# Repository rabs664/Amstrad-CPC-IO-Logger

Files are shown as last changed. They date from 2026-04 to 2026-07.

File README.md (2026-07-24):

# Amstrad-CPC-IO-Logger

V2_0

>[!CAUTION]
>USE AT YOUR OWN RISK.
>There is always the risk that this Amstrad CPC IO Logger could cause harm to your CPC. Although I have tested the Amstrad CPC IO Logger, there is no guarantee that it will work properly under all circumstances.

>[!WARNING]
>This project is still in development and has only been made public to share the ideas and solicit feedback. I am no expert in this area and the project should not be used as a baseline example but more an idea of what can be done with the Pico.

## Outline
This Amstrad CPC IO Logger is an external device which allows values written to the Gate Array and the CRTC to be retrieved. This can be useful, for example, for a debugger that exposes the state of these chips in a dedicated UI section.

Port &7F is used by the Gate Array and is write-only. On a standard Amstrad CPC, there is no ability to read back the values sent to the Gate Array (video mode, pen colours, ROM/RAM configuration, etc.). The firmware keeps a shadow copy of all written values in RAM for its own internal use, but many programs bypass the firmware entirely for such operations.

Port &BF can be used to read values from the CRTC, but only on certain CRTC types, and even then, only a subset of registers is readable. The firmware only maintains a shadow copy of R12–R13 (display start address). The remaining registers cannot be read back reliably across all machines, as behaviour varies depending on the CRTC type installed.

## Summary
The Amstrad CPC only uses the top 8 address lines, A8-A15, to address standard IO devices, as illustrated below. For more information please refer to the [CPC Wiki Default IO Port Summary page](https://www.cpcwiki.eu/index.php/Default_I/O_Port_Summary). To see a list of all known ports please refer to the [CPC Wiki IO Port Summary page](https://www.cpcwiki.eu/index.php/I/O_Port_Summary). This Amstrad CPC IO logger then captures A8-A15 and D0-D7 associated with any IO Write that occurs (i.e. a Z80 OUT instruction). Any IO Writes associated with the Gate Array or CRTC are captured and can be retrieved at any point with a series of simple IO Reads to the Amstrad CPC IO logger (i.e. a Z80 IN instruction).

Amstrad CPC IO Addressing

## Design Summary
The discrete 74 series logic associated with Amstrad CPC IO Logger PCB presents two signals* to the Pico;
- IOWR: Active low on an IO Write instruction from the Amstrad CPC
- CSRD: Active low when on an IO read instruction from the Amstrad CPC for the Amstrad CPC IO Logger IO Address.

Amstrad CPC IO Logger Design

### Capture
When IOWR goes low, State Machine 1 (SM1) will push the contents of A8-A15** and D0-D7 onto its RX FIFO. DMA1 detects this and places the data into a Capture Buffer. Note that the Capture buffer is configured as a Rig Buffer.

**A0-A1 are also capture but are not used.

The contents of the Capture Buffer is decoded and the CRTC and Gate Array Register write values are placed into a Register Buffer.

### Timing
When data is placed into the Capture Buffer it is timed stamped in the Timing Buffer with time since start in micro seconds.

### Retrieve
When CSRD goes low after an IN instruction (i.e. after INP(&F9E0) from BASIC), SM2 places a transfer count of 1 on it's RX FIFO. DMA2 detects this and places this value into the Transfer Count Trigger of DMA3. DMA3 detects this and then places the next register value from the Register Buffer onto the TX FIFO of SM2. This is then returned back to the Amstrad CPC. Repeated IN instructions will return the next value in the Register Buffer.

### Register Buffer
The Register Buffer is a sequential list of register values written to the CRTC and Gate Array. Each IN instruction to the Amstrad CPC IO Logger will return the next value in the Register Buffer. An OUT instruction of 0 (i.e. OUT &F9E0,0 from BASIC) will reset the sequence back to the first value in the Register Buffer (i.e. CRTC R0). Equally an OUT instruction of 0 to 43 will set the position in the Register Buffer from which the next IN instruction will retrieve data. Note the Register Buffer is 64 bytes in size and a Ring Buffer, so values past 43 (the ERR Register) will return an uninitialized value until the retrieval position wraps.

Register Buffer V2

- LR is the last CRTC Register written to.
- LP is the last GA Pen written to.
- P16 is the Border Pen
- ERR is a decode error flag generated by the Amstrad CPC IO Logger (still under development).

Please refer to the [CPC Wiki CRTC page](https://www.cpcwiki.eu/index.php/CRTC) and [CPC Wiki Gate Array page](https://www.cpcwiki.eu/index.php/Gate_Array) for more information.

### Pen Colour Values
The Pen Colour values returned do not include the 3 bit command value 010. See INKR Values in the Info folder. 

### Debug
Debug output to a console (i.e. putty) can be enabled within the code and controlled from the Amstrad CPC with an OUT instruction between 50 and 57 (i.e. OUT &F9E0,50 will print the contents of the Register Buffer to the console). See the main code for more information.

Debug

Debug commands.

| Debug |Value| Log Header |
| ---|-----|---|
| PRINT_REG_BUFFER | 50  | REGBF |
| TOGGLE_PRINT_CRTC_INDEX | 51  | CRTCI |
| TOGGLE_PRINT_CRTC_DATA | 52  | CRTCD |
| TOGGLE_GA_PEN | 53  | GAPEN |
| TOGGLE_GA_COL | 54  | GACOL |
| TOGGLE_GA_RMR | 55  | GARMR |
| TOGGLE_GA_MMR | 56  | GAMMR |
| TOGGLE_GA_RMR2 | 57  | GARM2 |
| TOGGLE_IO_LOG | 58  | IOLOG |
| TOGGLE_CRTC_DATA_TIMING_V1 | 59  | |
| TOGGLE_CRTC_DATA_TIMING_V2 | 60  | |

### CRTC Register Logging
IO Writes to the CRTC Register Logging can be enabled using OUT &F9E0,60 (OUT &F9E0,60 again will disable the logging).

When enabled the time stamped writes to the CRTC Registered will be loggged over USB. The logging includes a time since last write in micro seconds, the register number, the value written (in hex) and a "lag-o-meter".

The "lag-o-meter" is a value from 1 to 10 indicating the decode lag behind the capture. A value of 1 is no lag and a value of 10 implies the decode has been overrun and data may be lost.

CRTC Register Logging

### Debug Command Logging
The logging of debug Commands sent to the CPC IO Logger from the CPC using OUT &F9E0 can be enabled using OUT &F9E0,58.

## Testing
Only first pass testing has so far been completed on an Amstrad CPC 6128 but the concept is working. More comprehensive testing, including error conditions is still to be completed.

Below is the output from the sample BASIC program in the repository.

Example BASIC program

## IO Address
By default the IO address used in the repository is set to F9E0. The following IO Address can be selected

- F8E0
- F8F0
- F9E0
- F9F0

Address Jumper Settings

## Project History
### 06 June 2026
Removed V1.1 of the PCB
### 17 April 2026 
CRTC Register Logging
### 26 June 2026
Found a small problem with the IO Address Selection when sending Debug Commands to the Pico. see Issue 2 V2.0 in progress
### 24 July 2026
Updated V2.0 of the PCB

## Acknowledgements
- **NoRecess** for the inspiration and support on this project.
- **RHD** members for support and encouragement.
- **Petersfield Men's Shed IT and Electronics Group** members for support and encouragement.
- **CPC Wiki** for the great information.
- **TinWhisker** for the Simple Pico CDC example

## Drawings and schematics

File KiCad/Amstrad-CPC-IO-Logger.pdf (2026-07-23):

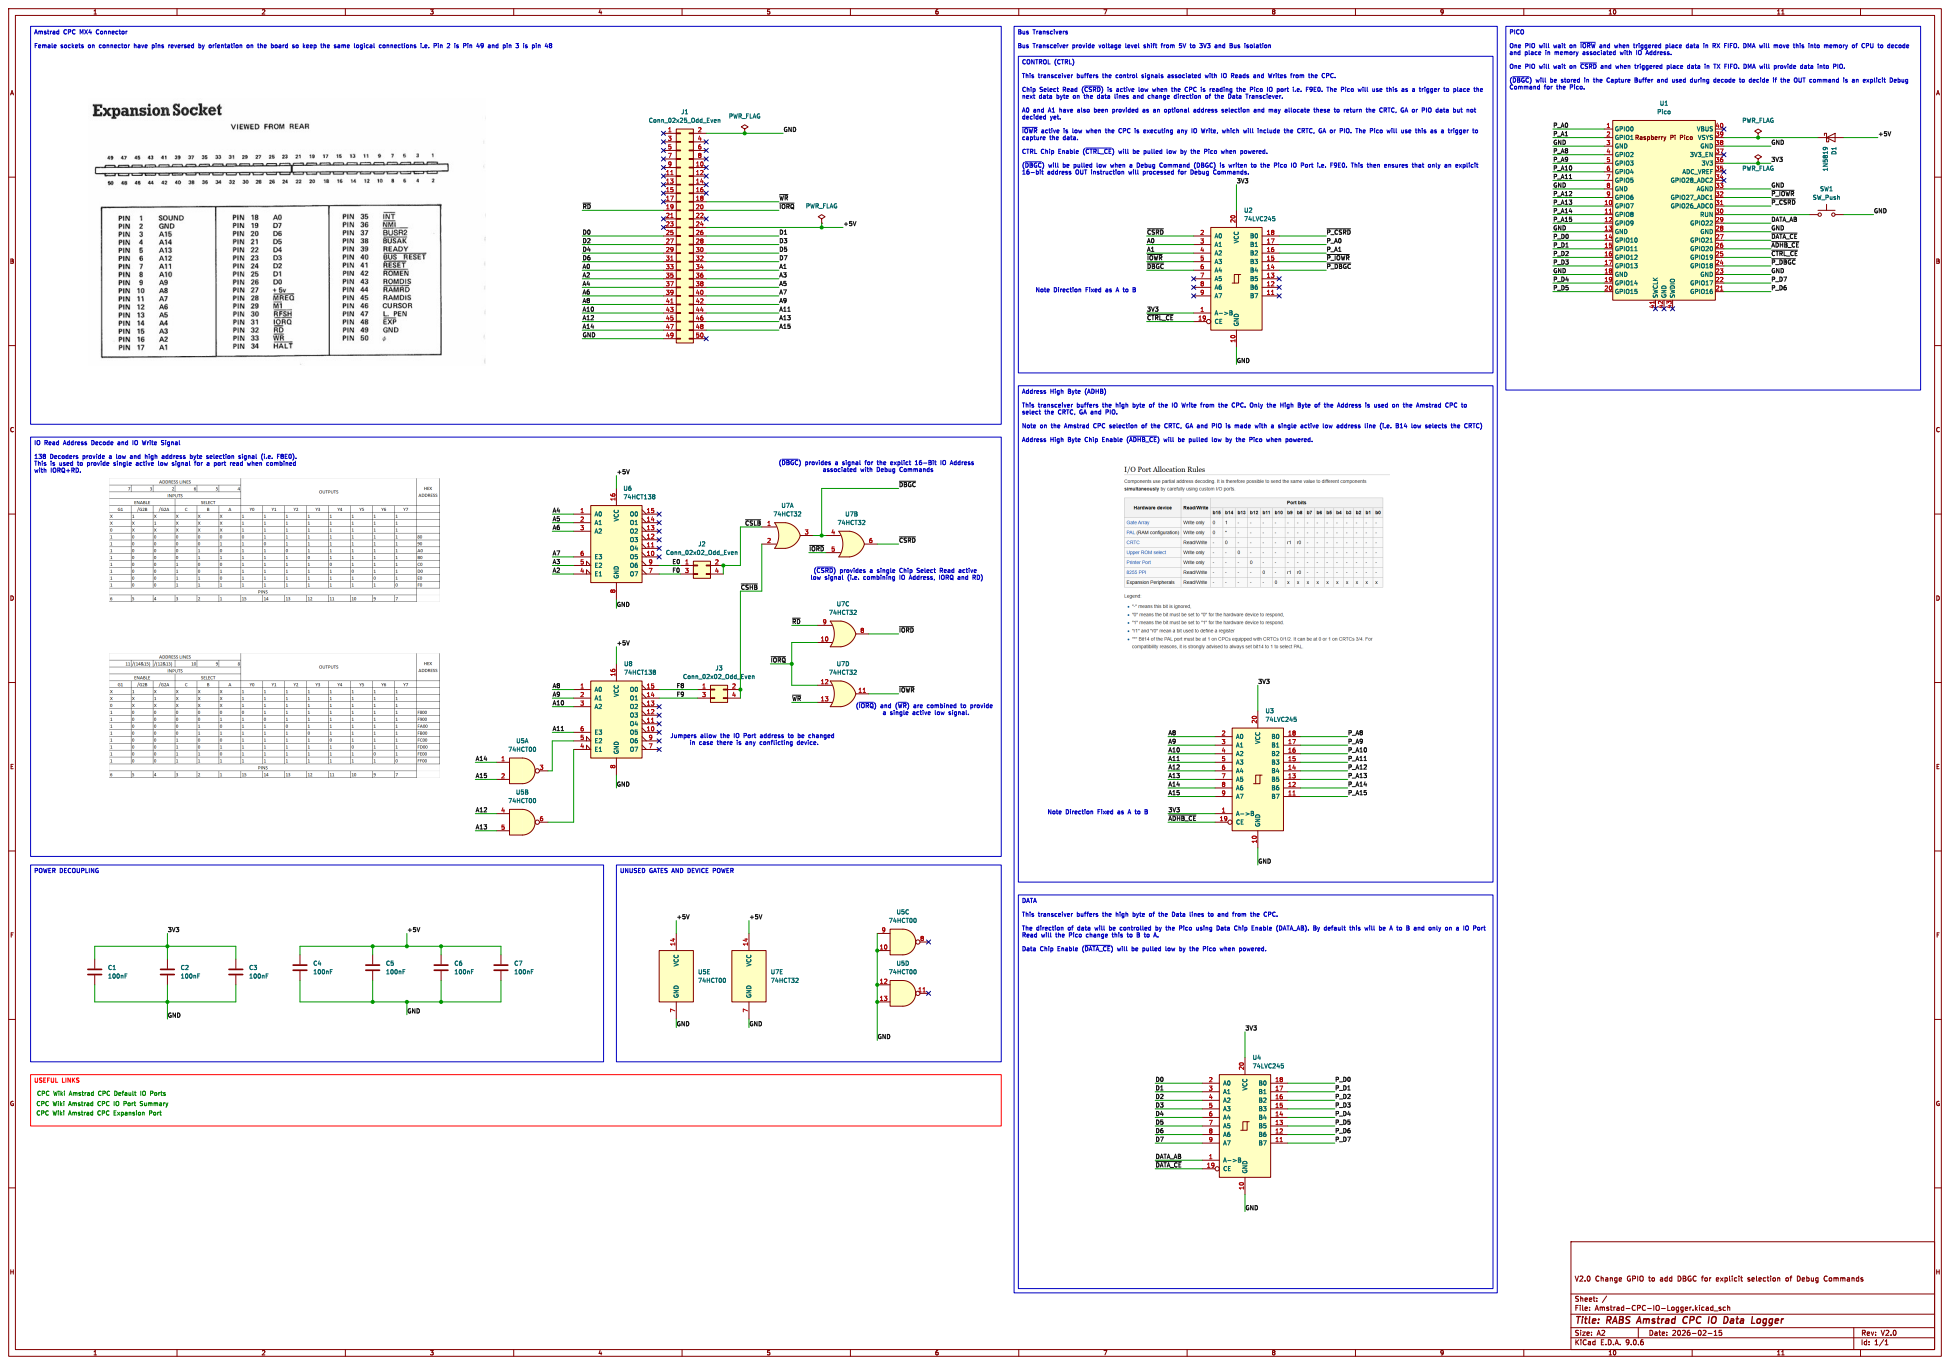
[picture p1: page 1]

capture the data. CTRL Chip Enable (~{CTRL_CE})will be pulled low by the Pico when powered.
~{CTRL_CE} 3V3 ~{IOWR} A0A1~{CSRD}

(~{CSRD})provides a single Chip Select Read active

a single active low signal.

Jumpers allow the IO Port address to be changed

CPC Wiki Amstrad CPC Default IO Ports (https://www.cpcwiki.eu/index.php/Default_I/O_Port_Summary)
CPC Wiki Amstrad CPC IO Port Summary (https://www.cpcwiki.eu/index.php/I/O_Port_Summary)

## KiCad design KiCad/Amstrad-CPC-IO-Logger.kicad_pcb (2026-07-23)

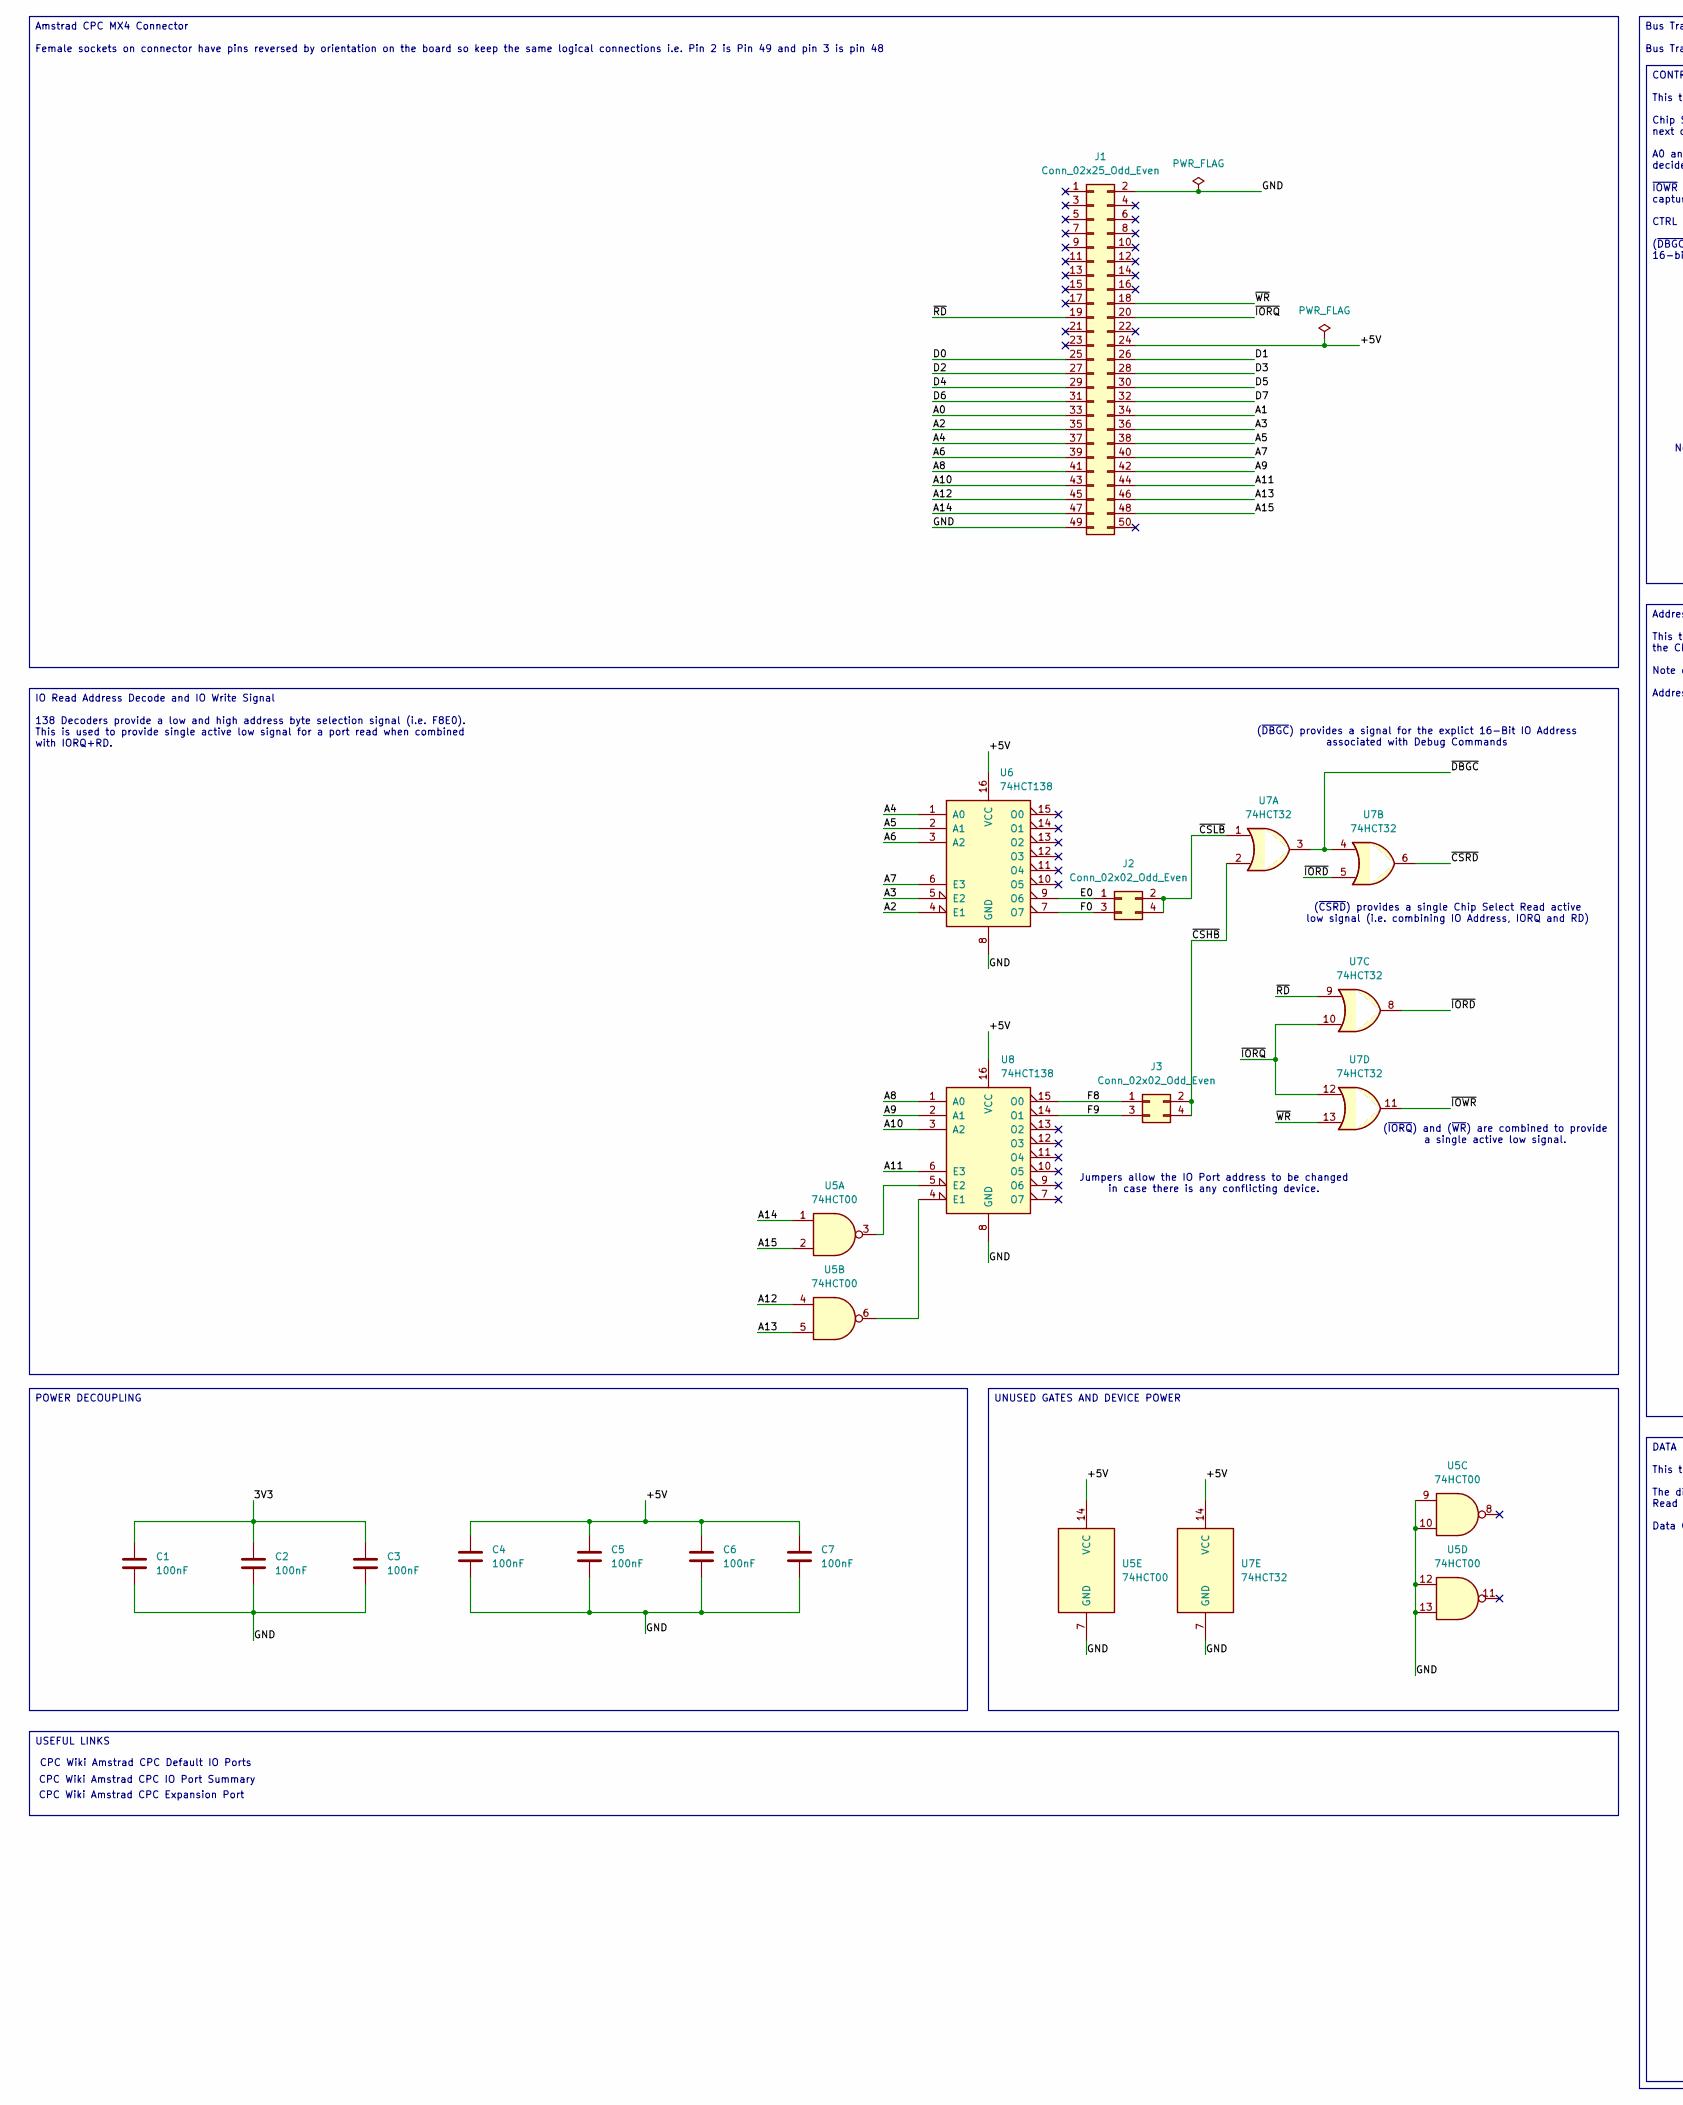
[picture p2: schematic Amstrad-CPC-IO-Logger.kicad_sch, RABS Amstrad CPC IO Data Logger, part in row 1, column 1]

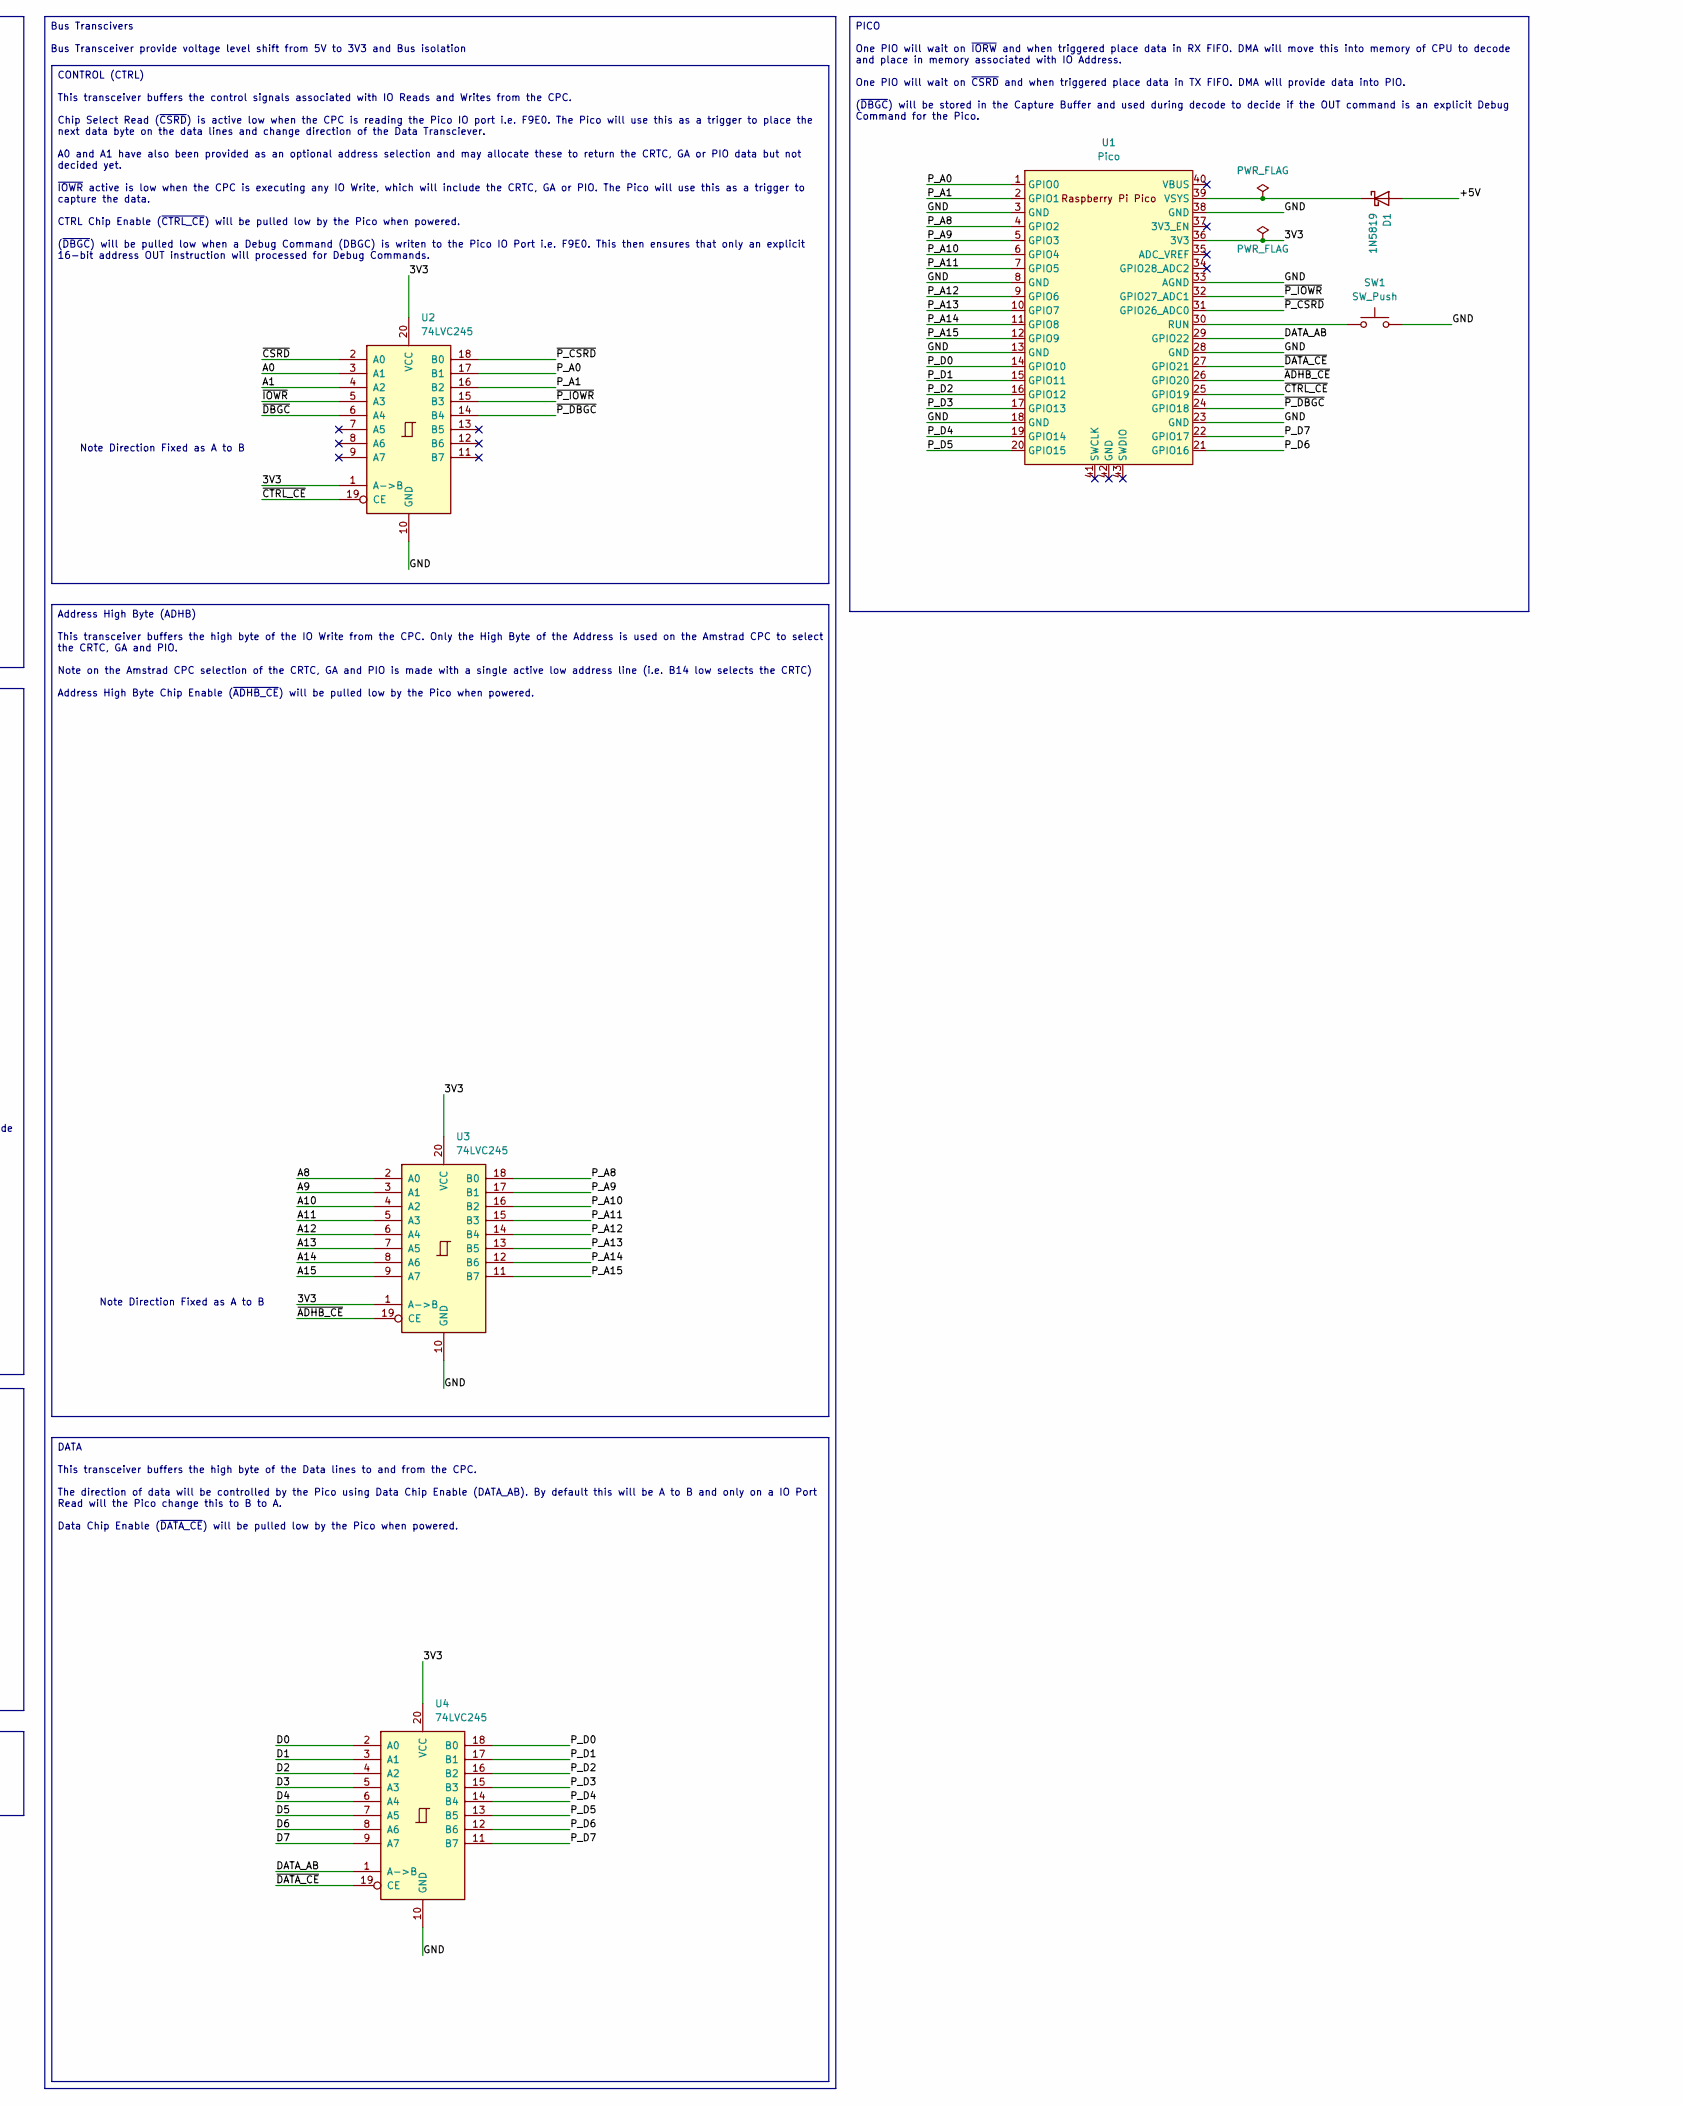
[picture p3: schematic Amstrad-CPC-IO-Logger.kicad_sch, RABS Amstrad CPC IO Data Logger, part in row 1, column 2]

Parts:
C1, C2, C3, C4, C5, C6, C7: 100nF; C_Disc_D5.0mm_W2.5mm_P5.00mm; DigiKey 56-K104K15X7RF53H5G-ND
D1: 1N5819; D_DO-41_SOD81_P10.16mm_Horizontal
J1: Conn_02x25_Odd_Even; IDC-Header_2x25_P2.54mm_Horizontal; DigiKey 3M157291-ND
J2, J3: Conn_02x02_Odd_Even; PinHeader_2x02_P2.54mm_Vertical
SW1: SW_Push; SW_PUSH_6mm
U1: Pico; RPi_Pico_SMD_TH
U2, U3, U4: 74LVC245; DIP-20_W7.62mm_Socket_LongPads
U5: 74HCT00; DIP-14_W7.62mm_Socket_LongPads; DigiKey 296-2081-5-ND
U6, U8: 74HCT138; DIP-16_W7.62mm_Socket_LongPads; DigiKey 296-2091-5-ND
U7: 74HCT32; DIP-14_W7.62mm_Socket_LongPads; Digikey 296-2112-5-ND

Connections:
/3V3: C1.1, C2.1, C3.1, U1.36 (3V3), U2.1 (A->B), U2.20 (VCC), U3.1 (A->B), U3.20 (VCC), U4.20 (VCC)
/+5V: C4.1, C5.1, C6.1, C7.1, D1.2 (A), J1.24, U5.14 (VCC), U6.16 (VCC), U7.14 (VCC), U8.16 (VCC)
/A0: J1.33, U2.3 (A1)
/A1: J1.34, U2.4 (A2)
/A2: J1.35, U6.4 (E1)
/A3: J1.36, U6.5 (E2)
/A4: J1.37, U6.1 (A0)
/A5: J1.38, U6.2 (A1)
/A6: J1.39, U6.3 (A2)
/A7: J1.40, U6.6 (E3)
/A8: J1.41, U3.2 (A0), U8.1 (A0)
/A9: J1.42, U3.3 (A1), U8.2 (A1)
/A10: J1.43, U3.4 (A2), U8.3 (A2)
/A11: J1.44, U3.5 (A3), U8.6 (E3)
/A12: J1.45, U3.6 (A4), U5.4
/A13: J1.46, U3.7 (A5), U5.5
/A14: J1.47, U3.8 (A6), U5.1
/A15: J1.48, U3.9 (A7), U5.2
/D0: J1.25, U4.2 (A0)
/D1: J1.26, U4.3 (A1)
/D2: J1.27, U4.4 (A2)
/D3: J1.28, U4.5 (A3)
/D4: J1.29, U4.6 (A4)
/D5: J1.30, U4.7 (A5)
/D6: J1.31, U4.8 (A6)
/D7: J1.32, U4.9 (A7)
/DATA_AB: U1.29 (GPIO22), U4.1 (A->B)
/E0: J2.1, U6.9 (O6)
/F0: J2.3, U6.7 (O7)
/F8: J3.1, U8.15 (O0)
/F9: J3.3, U8.14 (O1)
/GND: C1.2, C2.2, C3.2, C4.2, C5.2, C6.2, C7.2, J1.2, J1.49, SW1.2, U1.3 (GND), U1.8 (GND), U1.13 (GND), U1.18 (GND), U1.23 (GND), U1.28 (GND), U1.33 (AGND), U1.38 (GND), U2.10 (GND), U3.10 (GND), U4.10 (GND), U5.7 (GND), U5.9, U5.10, U5.12, U5.13, U6.8 (GND), U7.7 (GND), U8.8 (GND)
/P_A0: U1.1 (GPIO0), U2.17 (B1)
/P_A1: U1.2 (GPIO1), U2.16 (B2)
/P_A8: U1.4 (GPIO2), U3.18 (B0)
/P_A9: U1.5 (GPIO3), U3.17 (B1)
/P_A10: U1.6 (GPIO4), U3.16 (B2)
/P_A11: U1.7 (GPIO5), U3.15 (B3)
/P_A12: U1.9 (GPIO6), U3.14 (B4)
/P_A13: U1.10 (GPIO7), U3.13 (B5)
/P_A14: U1.11 (GPIO8), U3.12 (B6)
/P_A15: U1.12 (GPIO9), U3.11 (B7)
/P_D0: U1.14 (GPIO10), U4.18 (B0)
/P_D1: U1.15 (GPIO11), U4.17 (B1)
/P_D2: U1.16 (GPIO12), U4.16 (B2)
/P_D3: U1.17 (GPIO13), U4.15 (B3)
/P_D4: U1.19 (GPIO14), U4.14 (B4)
/P_D5: U1.20 (GPIO15), U4.13 (B5)
/P_D6: U1.21 (GPIO16), U4.12 (B6)
/P_D7: U1.22 (GPIO17), U4.11 (B7)
/~ADHB_CE: U1.26 (GPIO20), U3.19 (CE)
/~CSHB: J3.2, J3.4, U7.2
/~CSLB: J2.2, J2.4, U7.1
/~CSRD: U2.2 (A0), U7.6
/~CTRL_CE: U1.25 (GPIO19), U2.19 (CE)
/~DATA_CE: U1.27 (GPIO21), U4.19 (CE)
/~DBGC: U2.6 (A4), U7.3, U7.4
/~IORD: U7.5, U7.8
/~IORQ: J1.20, U7.10, U7.12
/~IOWR: U2.5 (A3), U7.11
/~P_CSRD: U1.31 (GPIO26_ADC0), U2.18 (B0)
/~P_DBGC: U1.24 (GPIO18), U2.14 (B4)
/~P_IOWR: U1.32 (GPIO27_ADC1), U2.15 (B3)
/~RD: J1.19, U7.9
/~WR: J1.18, U7.13
unnamed: D1.1 (K), U1.39 (VSYS)
unnamed: SW1.1, U1.30 (RUN)
unnamed: U5.6, U8.4 (E1)
unnamed: U5.3, U8.5 (E2)

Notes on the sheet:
CPC Wiki Amstrad CPC Expansion Port
CPC Wiki Amstrad CPC IO Port Summary
Note Direction Fixed as A to B
(~{CSRD}) provides a single Chip Select Read active low signal (i.e. combining IO Address, IORQ and RD)
(~{IORQ}) and (~{WR}) are combined to provide a single active low signal.
CPC Wiki Amstrad CPC Default IO Ports
Jumpers allow the IO Port address to be changed in case there is any conflicting device.
(~{DBGC}) provides a signal for the explict 16-Bit IO Address associated with Debug Commands
Amstrad CPC MX4 Connector Female sockets on connector have pins reversed by orientation on the board so keep the same logical connections i.e. Pin 2 is Pin 49 and pin 3 is pin 48
USEFUL LINKS
UNUSED GATES AND DEVICE POWER
PICO One PIO will wait on ~{IORW} and when triggered place data in RX FIFO. DMA will move this into memory of CPU to decode and place in memory associated with IO Address. One PIO will wait on ~{CSRD} and when triggered place data in TX FIFO. DMA will provide data into PIO. (~{DBGC}) will be stored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
CONTROL (CTRL) This transceiver buffers the control signals associated with IO Reads and Writes from the CPC. Chip Select Read (~{CSRD}) is active low when the CPC is reading the Pico IO port i.e. F9E0. The Pico will use this as a trigger to place the next data byte on the data lines and change dir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
Address High Byte (ADHB) This transceiver buffers the high byte of the IO Write from the CPC. Only the High Byte of the Address is used on the Amstrad CPC to select the CRTC, GA and PIO. Note on the Amstrad CPC selection of the CRTC, GA and PIO is made with a single active low address line (i.e. B1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
DATA This transceiver buffers the high byte of the Data lines to and from the CPC. The direction of data will be controlled by the Pico using Data Chip Enable (DATA_AB). By default this will be A to B and only on a IO Port Read will the Pico change this to B to A. Data Chip Enable (~{DATA_CE}) will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
POWER DECOUPLING
IO Read Address Decode and IO Write Signal 138 Decoders provide a low and high address byte selection signal (i.e. F8E0). This is used to provide single active low signal for a port read when combined with IORQ+RD.
Bus Transcivers Bus Transceiver provide voltage level shift from 5V to 3V3 and Bus isolation

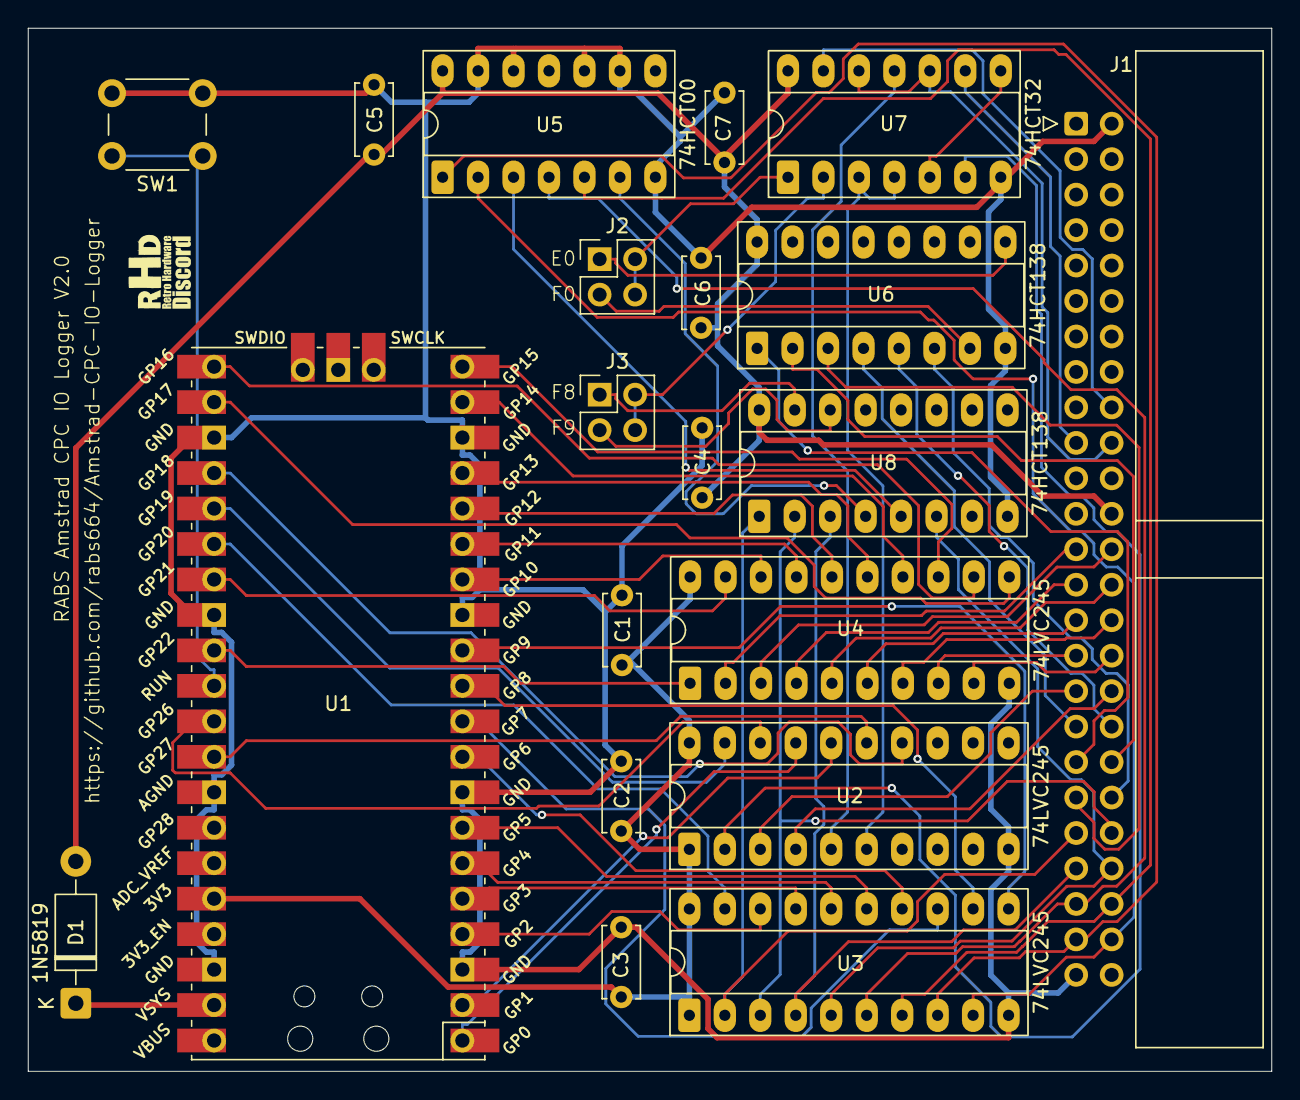
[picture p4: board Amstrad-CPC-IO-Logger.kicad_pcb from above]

Board: 2 copper layers, 89.1 x 74.7 mm, 20 parts (0 on the bottom side), 69 nets.

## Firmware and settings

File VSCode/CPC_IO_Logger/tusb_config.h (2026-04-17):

/*
 * The MIT License (MIT)
 *
 * Copyright (c) 2019 Ha Thach (tinyusb.org)
 *
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
 */

#ifndef _TUSB_CONFIG_H_
#define _TUSB_CONFIG_H_

#ifdef __cplusplus
  extern "C" {
#endif

//--------------------------------------------------------------------
// COMMON CONFIGURATION
//--------------------------------------------------------------------

// RHPort number used for device can be defined by board.mk, default to port 0
#ifndef BOARD_DEVICE_RHPORT_NUM
  #define BOARD_DEVICE_RHPORT_NUM     0
#endif

// RHPort max operational speed can defined by board.mk
// Default to Highspeed for MCU with internal HighSpeed PHY (can be port specific), otherwise FullSpeed
#ifndef BOARD_DEVICE_RHPORT_SPEED
  #define BOARD_DEVICE_RHPORT_SPEED   OPT_MODE_HIGH_SPEED
#endif

// Device mode with rhport and speed defined by board.mk
#if   BOARD_DEVICE_RHPORT_NUM == 0
  #define CFG_TUSB_RHPORT0_MODE     (OPT_MODE_DEVICE | BOARD_DEVICE_RHPORT_SPEED)
#elif BOARD_DEVICE_RHPORT_NUM == 1
  #define CFG_TUSB_RHPORT1_MODE     (OPT_MODE_DEVICE | BOARD_DEVICE_RHPORT_SPEED)
#else
  #error "Incorrect RHPort configuration"
#endif

#ifndef CFG_TUSB_OS
  #define CFG_TUSB_OS               OPT_OS_NONE
#endif

//--------------------------------------------------------------------
// DEVICE CONFIGURATION
//--------------------------------------------------------------------

#ifndef CFG_TUD_ENDPOINT0_SIZE
  #define CFG_TUD_ENDPOINT0_SIZE    64
#endif

//------------- CLASS -------------//
#define CFG_TUD_CDC               1
#define CFG_TUD_MSC               0
#define CFG_TUD_HID               1
#define CFG_TUD_MIDI              0
#define CFG_TUD_VENDOR            0

// HID buffer size Should be sufficient to hold ID (if any) + Data
#define CFG_TUD_HID_EP_BUFSIZE    64

// CDC FIFO size of TX and RX
//#define CFG_TUD_CDC_RX_BUFSIZE   (TUD_OPT_HIGH_SPEED ? 512 : 64)
//#define CFG_TUD_CDC_TX_BUFSIZE   (TUD_OPT_HIGH_SPEED ? 512 : 64)

// CDC Endpoint transfer buffer size, more is faster
//#define CFG_TUD_CDC_EP_BUFSIZE   (TUD_OPT_HIGH_SPEED ? 512 : 64)

#define CFG_TUD_CDC_RX_BUFSIZE   4096
#define CFG_TUD_CDC_TX_BUFSIZE   4096

// CDC Endpoint transfer buffer size, more is faster
#define CFG_TUD_CDC_EP_BUFSIZE   4096


#ifdef __cplusplus
 }
#endif

#endif /* _TUSB_CONFIG_H_ */

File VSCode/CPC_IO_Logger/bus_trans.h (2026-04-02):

// Bus Transceiver functions and definitions
//
// This file contains the definitions and functions for controlling the bus transceivers
// that are used to interface with the Amstrad CPC. 
//
// The bus transceivers are used to control the direction and enable/disable the data bus, 
// as well as to control the address high byte and control signals. 
//
// The functions in this file will be used to set up the bus transceivers and to control the 
// data bus direction and enable/disable the data bus as needed.    
//
// There are three bus transceivers used in this project:
// 1. Control (CTRL) - This transceiver is used to control the enable/disable of the data bus and to control the direction of the data bus.
// 2. Address High Byte (ADHB) - This transceiver is used to control the address high byte signals.
// 3. Data (DATA) - This transceiver is used to control the data bus signals. 
//
// All three transceivers are controlled using GPIO pins on the Raspberry Pi Pico, 
// and the functions in this file will use the GPIO library to control these pins.
//
// The GPIO pins used for the transceivers are defined as follows:
// CTRL_CE_GPIO - This GPIO pin is used to control the enable/disable of the control transceiver.
// ADHB_CE_GPIO - This GPIO pin is used to control the enable/disable of the address high byte transceiver.
// DATA_CE_GPIO - This GPIO pin is used to control the enable/disable of the data transceiver.
// DATA_DIR_GPIO - This GPIO pin is used to control the direction of the data bus.
//
// The Data Bus direction can be set to either CPC_TO_PICO or PICO_TO_CPC, depending on whether 
// the data is being read from the CPC or written to the CPC.
//
// Below is the layout of the three transceivers and their connections to the GPIO pins:
// 
//         +-----------------------------+
//         |        Control (CTRL)       |
//         |                             |
//         |        CE GPIO: 0           |
//         +-----------------------------+
//         |   Address High Byte (ADHB)  |
//         |                             |
//         |        CE GPIO: 1           |
//         +-----------------------------+
//         |          Data (DATA)        |
//         |                             |
//         |        CE GPIO: 2           |
//         |      Direction GPIO: 3      |
//         +-----------------------------+
//
// Below is layout of the signals conencted to the bus transceivers:
//
//         +-----------------------------+
//         |        Control (CTRL)       |
//         |                             |
//         |        CSRD GPIO: 22        |
//         |        IOWR GPIO: 26        |
//         |        A0   GPIO: 0         |
//         |        A1   GPIO: 1         |
//         +-----------------------------+
//
//         +-----------------------------+
//         |   Address High Byte (ADHB)  |
//         |                             |
//         |        A8   GPIO: 2         |
//         |        A9   GPIO: 3         |
//         |        A10  GPIO: 4         | 
//         |        A11  GPIO: 5         |
//         |        A12  GPIO: 6         |
//         |        A13  GPIO: 7         |
//         |        A14  GPIO: 8         |
//         |        A15  GPIO: 9         |
//         +-----------------------------+
//
//         +-----------------------------+
//         |          Data (DATA)        |
//         |                             |
//         |        D0   GPIO: 10        |
//         |        D1   GPIO: 11        |
//         |        D2   GPIO: 12        |
//         |        D3   GPIO: 13        |
//         |        D4   GPIO: 14        |
//         |        D5   GPIO: 15        |
//         |        D6   GPIO: 16        |
//         |        D7   GPIO: 27        |
//         +-----------------------------+
//


#define ENABLE 0
#define DISABLE 1

// Bus Transceier Direction Control
#define DATA_DIR_GPIO 21

#define CPC_TO_PICO 1
#define PICO_TO_CPC 0

// Bus Transceier setup
// Enable the three bus transceivers
void setup_bus_trans(void);

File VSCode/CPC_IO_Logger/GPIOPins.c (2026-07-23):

/* GPIO Pins for CPC IO Logger */

#include "GPIOPins.h"

void setup_gpio_pins(PIO pio) {
    // PIO IN pins GPIO 0 to GPIO 17 = A0..A1 + A8..A15 + D0..D7 + DBGC
    for (int i = P_A0; i <= P_DBGC; i++) {
        pio_gpio_init(pio,i);
    }

    // GPIO 27 = IOWR, value 0 = active
    pio_gpio_init(pio,P_IOWR);

    // GPIO 22 = DATA_AB, value of 1 = CPC to PICO, 0 = PICO to CPC
    pio_gpio_init(pio,P_DATA_AB);

    // GPIO 26 = CSRD, value 0 = active
    pio_gpio_init(pio,P_CSRD);

}

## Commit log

2026-04-02 Add readme for KiCad project
2026-04-06 Added delay after OUT to IO Logger to allow for delay because of debug print statements. Also fixed wrong toggle switch for CRTCI and CRTCD.
2026-04-28 PCB Update to move the Pico to the edge of the PCB.
    [Amstrad-CPC-IO-Logger-B_Cu.gbr, Amstrad-CPC-IO-Logger-B_Mask.gbr, Amstrad-CPC-IO-Logger-B_Paste.gbr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]
2026-06-06 Delete KiCad/Amstrad-CPC-IO-Logger-Gerbers-V1_1.zip
    Removed previous V1.1 of PCB
2026-06-06 Delete KiCad/Amstrad-CPC-IO-Logger-Gerbers-V1_1 directory
    Removed version 1.1 of PCB
    [Amstrad-CPC-IO-Logger-B_Cu.gbr, Amstrad-CPC-IO-Logger-B_Mask.gbr, Amstrad-CPC-IO-Logger-B_Paste.gbr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]
2026-06-25 Added excel info sheet on INKR Values
    [INKR Values.xlsx]
2026-07-23 Modifications for V2.0
    [Amstrad-CPC-IO-Logger-B_Cu.gbr, Amstrad-CPC-IO-Logger-B_Mask.gbr, Amstrad-CPC-IO-Logger-B_Paste.gbr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]
2026-07-24 Update for V2.0
    [INKR Values.xlsx]
